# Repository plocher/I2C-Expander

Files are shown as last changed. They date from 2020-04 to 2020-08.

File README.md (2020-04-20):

# I2C-9555
## License: CERN Open Hardware Licence v1.2

I2C PCF9555 / or / MCP23017 -based IO Expander with 4x IOB connections

This board can host either the MCP23017 or PCA9555 SO package chips.
The difference in proice is slight (~$0.50 or less), but the chips have slightly different programming and 
features, which may make one more desirable.  Rather than support 2x designs, it is easier to have one.

This is a 16-bit I/O board with 2x 8-bit ports: port0 and port1.

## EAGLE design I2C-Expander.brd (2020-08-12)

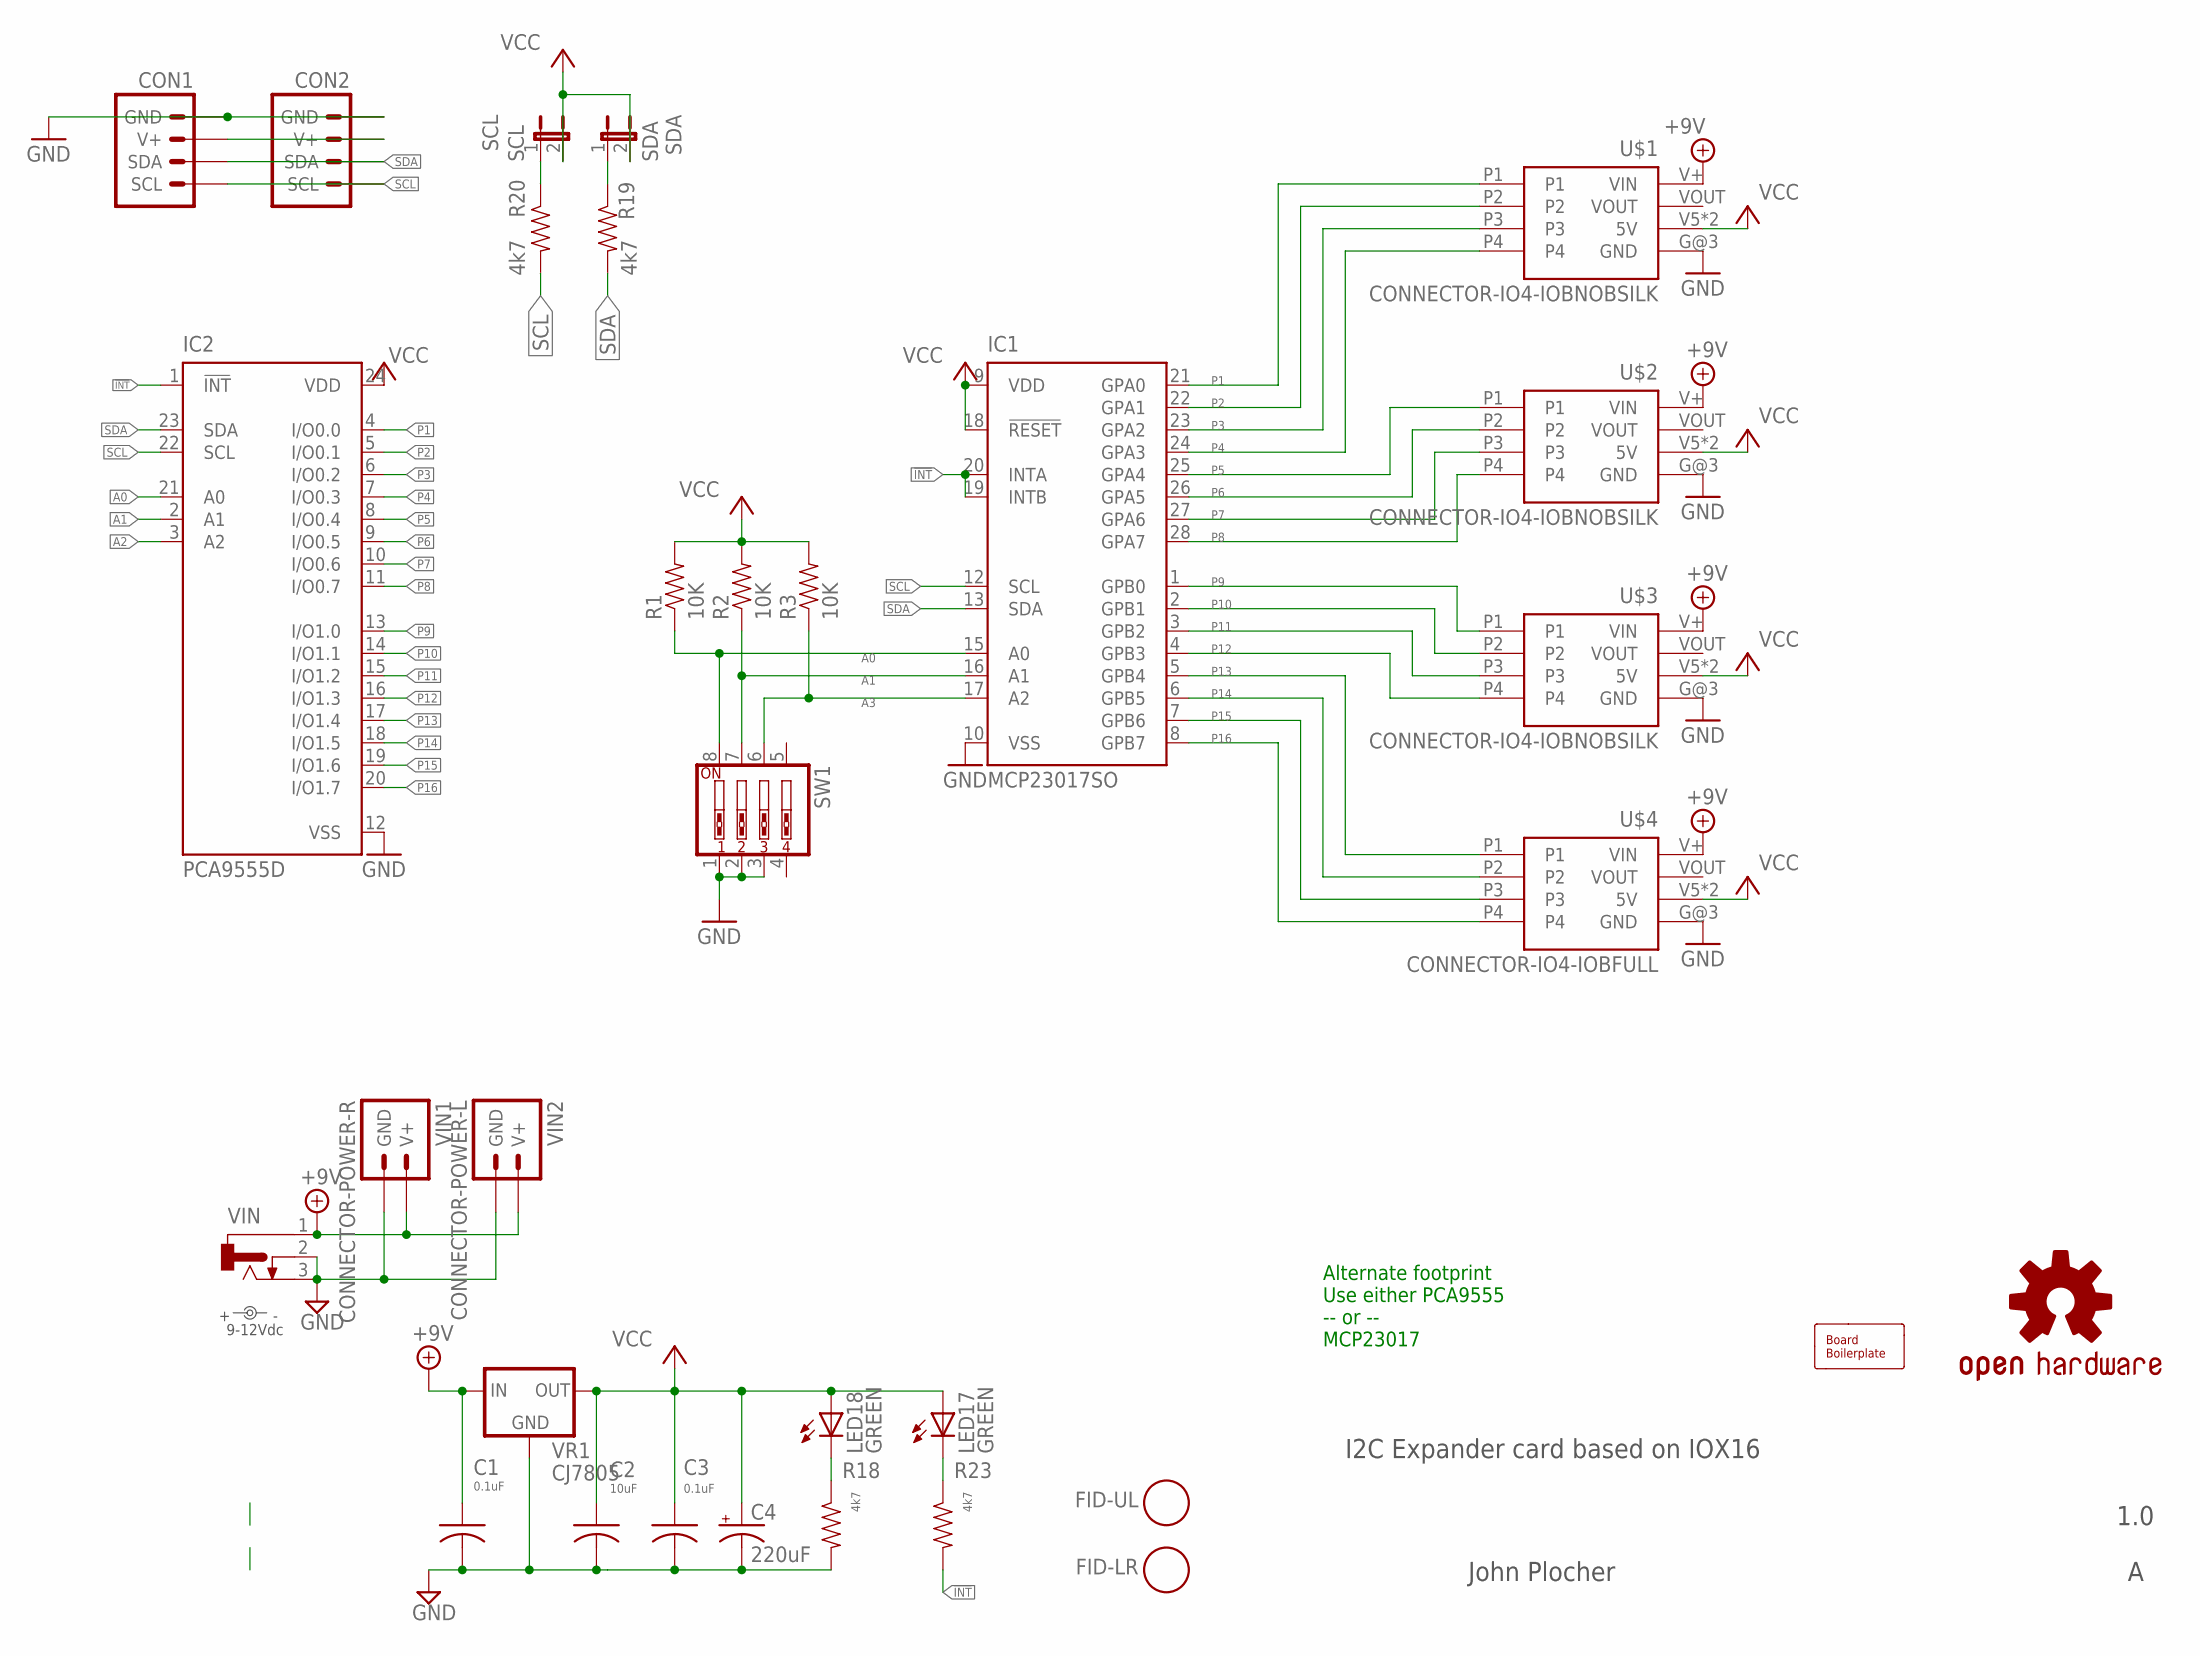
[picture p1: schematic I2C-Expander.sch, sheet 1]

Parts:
BOARD1: BOARD80X100-IOB; BOARD-DINRAIL-3.17IN-IOB
C1, C3: 0.1uF; 0805-CAP
C2: 10uF; 0805-CAP
C4: 220uF; 0810-CAP
CON1, CON2: CONNECTOR-I2CLEFT; I2C-L
FID-LR: FIDUCIAL; FIDUCIAL_1MM
FID-UL: FIDUCIAL; FIDUCIAL_1MM
IC1: MCP23017SO; SO28W
IC2: PCA9555D; SO24
LED17, LED18: GREEN; 0603-LED
OSHW1: DOC-OSHW-LOGO-M; OSHW-LOGO-M
POWER: 9-12Vdc; PWR_LABEL
R1, R2, R3: 10K; 0603-RES
R18, R19, R20, R23: 4k7; 0603-RES
SCL: SCL; 1X02_LOCK
SDA: SDA; 1X02_LOCK
SW1: SW_DIP-4; EDG-04
U$1, U$2, U$3: CONNECTOR-IO4-IOBNOBSILK; IOB-IO4-NOBOTSILK
U$4: CONNECTOR-IO4-IOBFULL; IO4-IOB
VIN: CONNECTOR-DC-POWER-RA; DCJ0202
VIN1: CONNECTOR-POWER-R; POWER-R
VIN2: CONNECTOR-POWER-L; POWER-R2
VR1: CJ7805; TO-252

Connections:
!INT: IC1.19 (INTB), IC1.20 (INTA), IC2.1 (!INT), R23.2
+9V: C1.1, U$1.V+ (VIN), U$2.V+ (VIN), U$3.V+ (VIN), U$4.V+ (VIN), VIN.1, VIN1.V+, VIN1.V+@1 (V+), VIN1.V+@2 (V+), VIN1.V+@3 (V+), VIN2.V+, VIN2.V+@1 (V+), VIN2.V+@2 (V+), VIN2.V+@3 (V+), VR1.1 (IN)
A0: IC1.15 (A0), IC2.21 (A0), R1.1, SW1.8
A1: IC1.16 (A1), IC2.2 (A1), R2.1, SW1.7
A2: IC2.3 (A2)
A3: IC1.17 (A2), R3.1, SW1.6
GND: C1.2, C2.2, C3.2, C4.-, CON1.GND, CON1.GND@1 (GND), CON2.GND, CON2.GND@1 (GND), IC1.10 (VSS), IC2.12 (VSS), R18.2, SW1.1, SW1.2, SW1.3, U$1.G@3 (GND), U$2.G@3 (GND), U$3.G@3 (GND), U$4.G@3 (GND), VIN.2, VIN.3, VIN1.GND, VIN1.GND@1 (GND), VIN1.GND@2 (GND), VIN1.GND@3 (GND), VIN2.GND, VIN2.GND@1 (GND), VIN2.GND@2 (GND), VIN2.GND@3 (GND), VR1.2 (GND); also elsewhere on the board
unnamed: CON1.V+, CON1.V+@1 (V+), CON2.V+, CON2.V+@1 (V+)
unnamed: LED17.C, R23.1
unnamed: R20.1, SCL.1
unnamed: R19.1, SDA.1
unnamed: LED18.C, R18.1
P1: IC1.21 (GPA0), IC2.4 (I/O0.0), U$1.P1; also elsewhere on the board
P2: IC1.22 (GPA1), IC2.5 (I/O0.1), U$1.P2; also elsewhere on the board
P3: IC1.23 (GPA2), IC2.6 (I/O0.2), U$1.P3; also elsewhere on the board
P4: IC1.24 (GPA3), IC2.7 (I/O0.3), U$1.P4; also elsewhere on the board
P5: IC1.25 (GPA4), IC2.8 (I/O0.4), U$2.P1; also elsewhere on the board
P6: IC1.26 (GPA5), IC2.9 (I/O0.5), U$2.P2; also elsewhere on the board
P7: IC1.27 (GPA6), IC2.10 (I/O0.6), U$2.P3; also elsewhere on the board
P8: IC1.28 (GPA7), IC2.11 (I/O0.7), U$2.P4; also elsewhere on the board
P9: IC1.1 (GPB0), IC2.13 (I/O1.0), U$3.P1; also elsewhere on the board
P10: IC1.2 (GPB1), IC2.14 (I/O1.1), U$3.P2; also elsewhere on the board
P11: IC1.3 (GPB2), IC2.15 (I/O1.2), U$3.P3; also elsewhere on the board
P12: IC1.4 (GPB3), IC2.16 (I/O1.3), U$3.P4; also elsewhere on the board
P13: IC1.5 (GPB4), IC2.17 (I/O1.4), U$4.P1; also elsewhere on the board
P14: IC1.6 (GPB5), IC2.18 (I/O1.5), U$4.P2; also elsewhere on the board
P15: IC1.7 (GPB6), IC2.19 (I/O1.6), U$4.P3; also elsewhere on the board
P16: IC1.8 (GPB7), IC2.20 (I/O1.7), U$4.P4; also elsewhere on the board
SCL: CON1.SCL, CON1.SCL@1 (SCL), CON2.SCL, CON2.SCL@1 (SCL), IC1.12 (SCL), IC2.22 (SCL), R20.2
SDA: CON1.SDA, CON1.SDA@1 (SDA), CON2.SDA, CON2.SDA@1 (SDA), IC1.13 (SDA), IC2.23 (SDA), R19.2
VCC: C2.1, C3.1, C4.+, IC1.9 (VDD), IC1.18 (!RESET), IC2.24 (VDD), LED17.A, LED18.A, R1.2, R2.2, R3.2, SCL.2, SDA.2, U$1.V5 (5V), U$1.V5@1 (5V), U$2.V5 (5V), U$2.V5@1 (5V), U$3.V5 (5V), U$3.V5@1 (5V), U$4.V5 (5V), U$4.V5@1 (5V), VR1.3 (OUT); also elsewhere on the board

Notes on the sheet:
I2C Expander card based on IOX16
1.0
John Plocher
Alternate footprint Use either PCA9555 -- or -- MCP23017

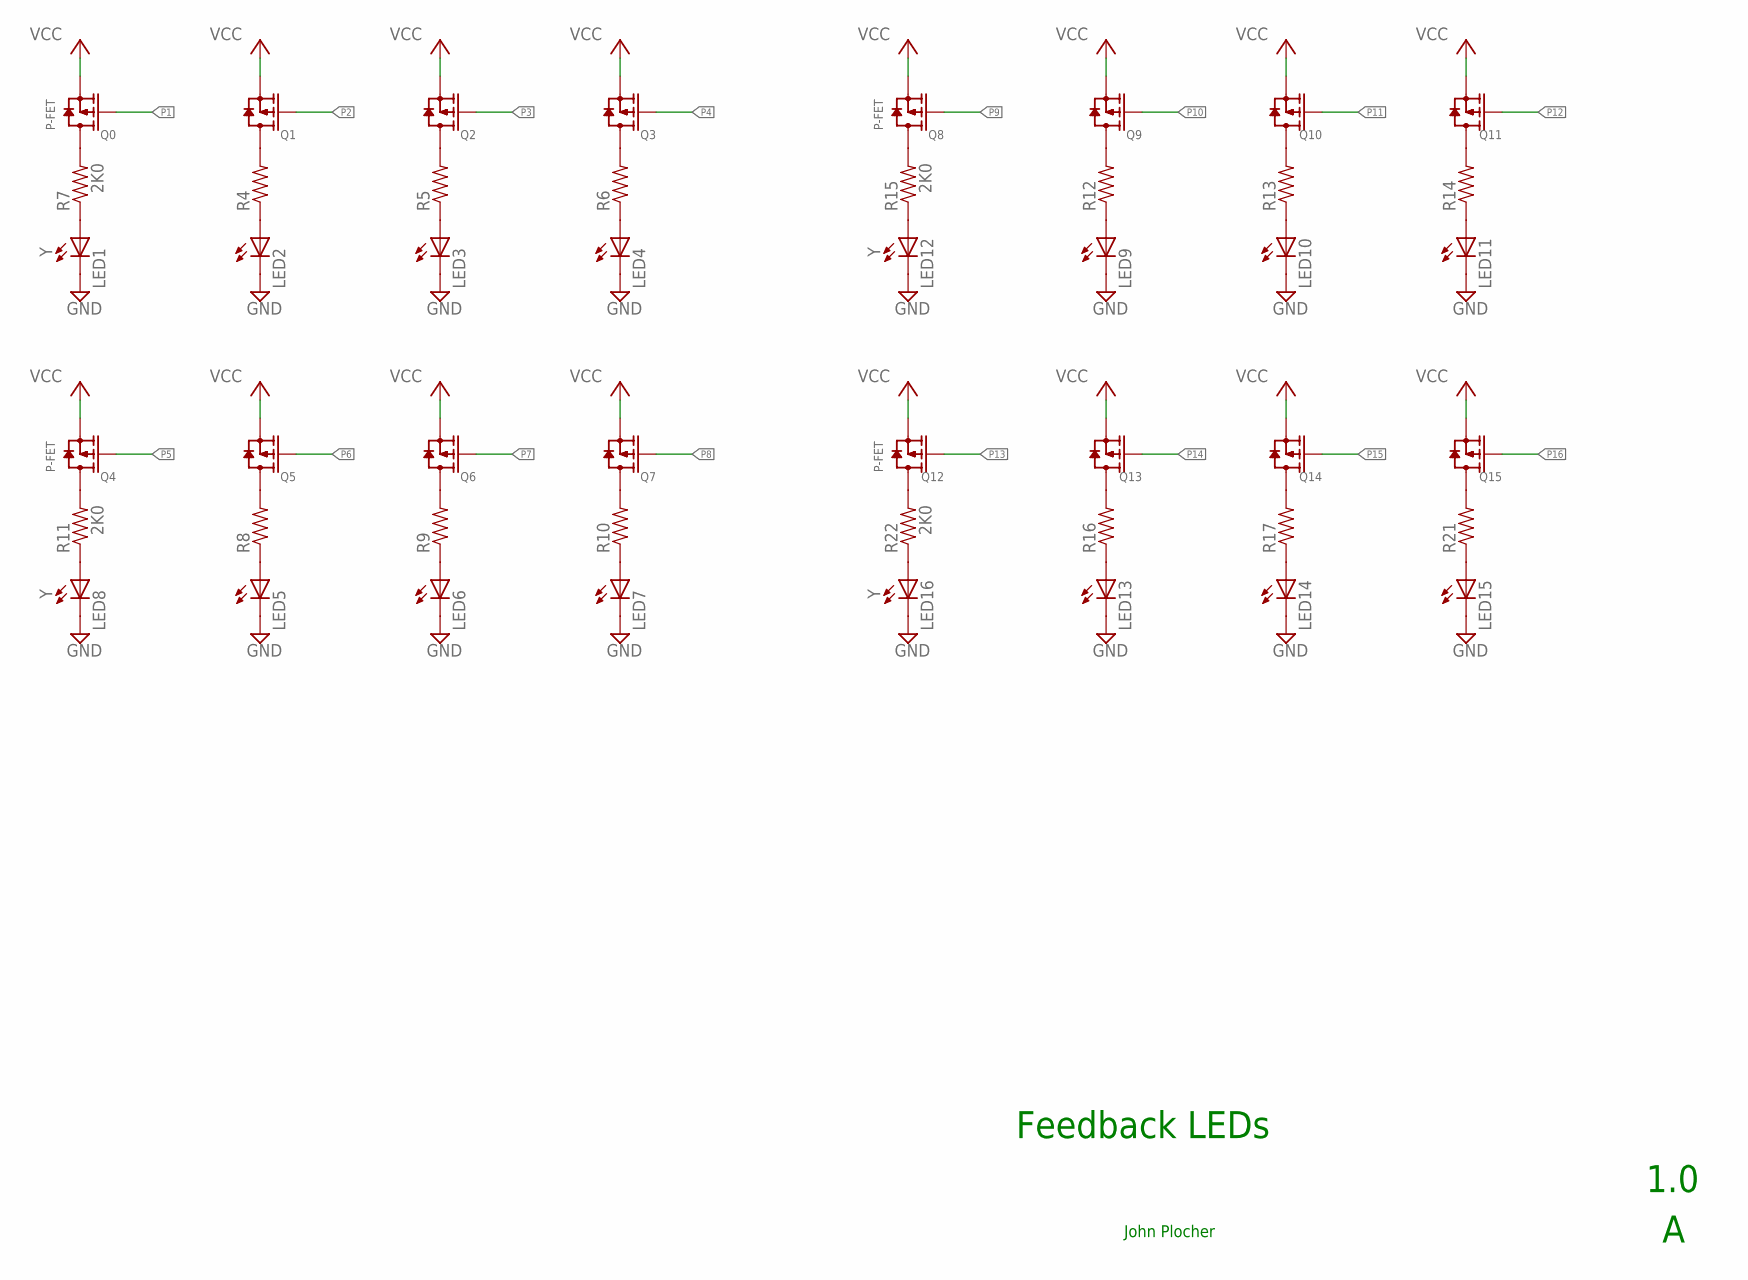
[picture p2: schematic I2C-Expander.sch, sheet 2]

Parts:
LED1, LED2, LED3, LED4, LED5, LED6, LED7, LED8, LED9, LED10, LED11, LED12, LED13, LED14, LED15, LED16: Y; 0603-LED
Q0, Q1, Q2, Q3, Q4, Q5, Q6, Q7, Q8, Q9, Q10, Q11, Q12, Q13, Q14, Q15: P-FET; SOT23
R4, R5, R6, R7, R8, R9, R10, R11, R12, R13, R14, R15, R16, R17, R21, R22: 2K0; 0805-RES

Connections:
GND: LED1.C, LED2.C, LED3.C, LED4.C, LED5.C, LED6.C, LED7.C, LED8.C, LED9.C, LED10.C, LED11.C, LED12.C, LED13.C, LED14.C, LED15.C, LED16.C; also elsewhere on the board
unnamed: Q4.3 (D), R11.2
unnamed: Q5.3 (D), R8.2
unnamed: Q6.3 (D), R9.2
unnamed: Q7.3 (D), R10.2
unnamed: LED8.A, R11.1
unnamed: LED5.A, R8.1
unnamed: LED6.A, R9.1
unnamed: LED7.A, R10.1
unnamed: Q8.3 (D), R15.2
unnamed: Q9.3 (D), R12.2
unnamed: Q10.3 (D), R13.2
unnamed: Q11.3 (D), R14.2
unnamed: LED12.A, R15.1
unnamed: LED9.A, R12.1
unnamed: LED10.A, R13.1
unnamed: LED11.A, R14.1
unnamed: Q12.3 (D), R22.2
unnamed: Q13.3 (D), R16.2
unnamed: Q14.3 (D), R17.2
unnamed: Q15.3 (D), R21.2
unnamed: LED16.A, R22.1
unnamed: LED13.A, R16.1
unnamed: LED14.A, R17.1
unnamed: LED15.A, R21.1
unnamed: Q0.3 (D), R7.2
unnamed: Q1.3 (D), R4.2
unnamed: Q2.3 (D), R5.2
unnamed: Q3.3 (D), R6.2
unnamed: LED1.A, R7.1
unnamed: LED2.A, R4.1
unnamed: LED3.A, R5.1
unnamed: LED4.A, R6.1
P1: Q0.1 (G); also elsewhere on the board
P2: Q1.1 (G); also elsewhere on the board
P3: Q2.1 (G); also elsewhere on the board
P4: Q3.1 (G); also elsewhere on the board
P5: Q4.1 (G); also elsewhere on the board
P6: Q5.1 (G); also elsewhere on the board
P7: Q6.1 (G); also elsewhere on the board
P8: Q7.1 (G); also elsewhere on the board
P9: Q8.1 (G); also elsewhere on the board
P10: Q9.1 (G); also elsewhere on the board
P11: Q10.1 (G); also elsewhere on the board
P12: Q11.1 (G); also elsewhere on the board
P13: Q12.1 (G); also elsewhere on the board
P14: Q13.1 (G); also elsewhere on the board
P15: Q14.1 (G); also elsewhere on the board
P16: Q15.1 (G); also elsewhere on the board
VCC: Q0.2 (S), Q1.2 (S), Q2.2 (S), Q3.2 (S), Q4.2 (S), Q5.2 (S), Q6.2 (S), Q7.2 (S), Q8.2 (S), Q9.2 (S), Q10.2 (S), Q11.2 (S), Q12.2 (S), Q13.2 (S), Q14.2 (S), Q15.2 (S); also elsewhere on the board

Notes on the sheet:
Feedback LEDs
1.0
John Plocher

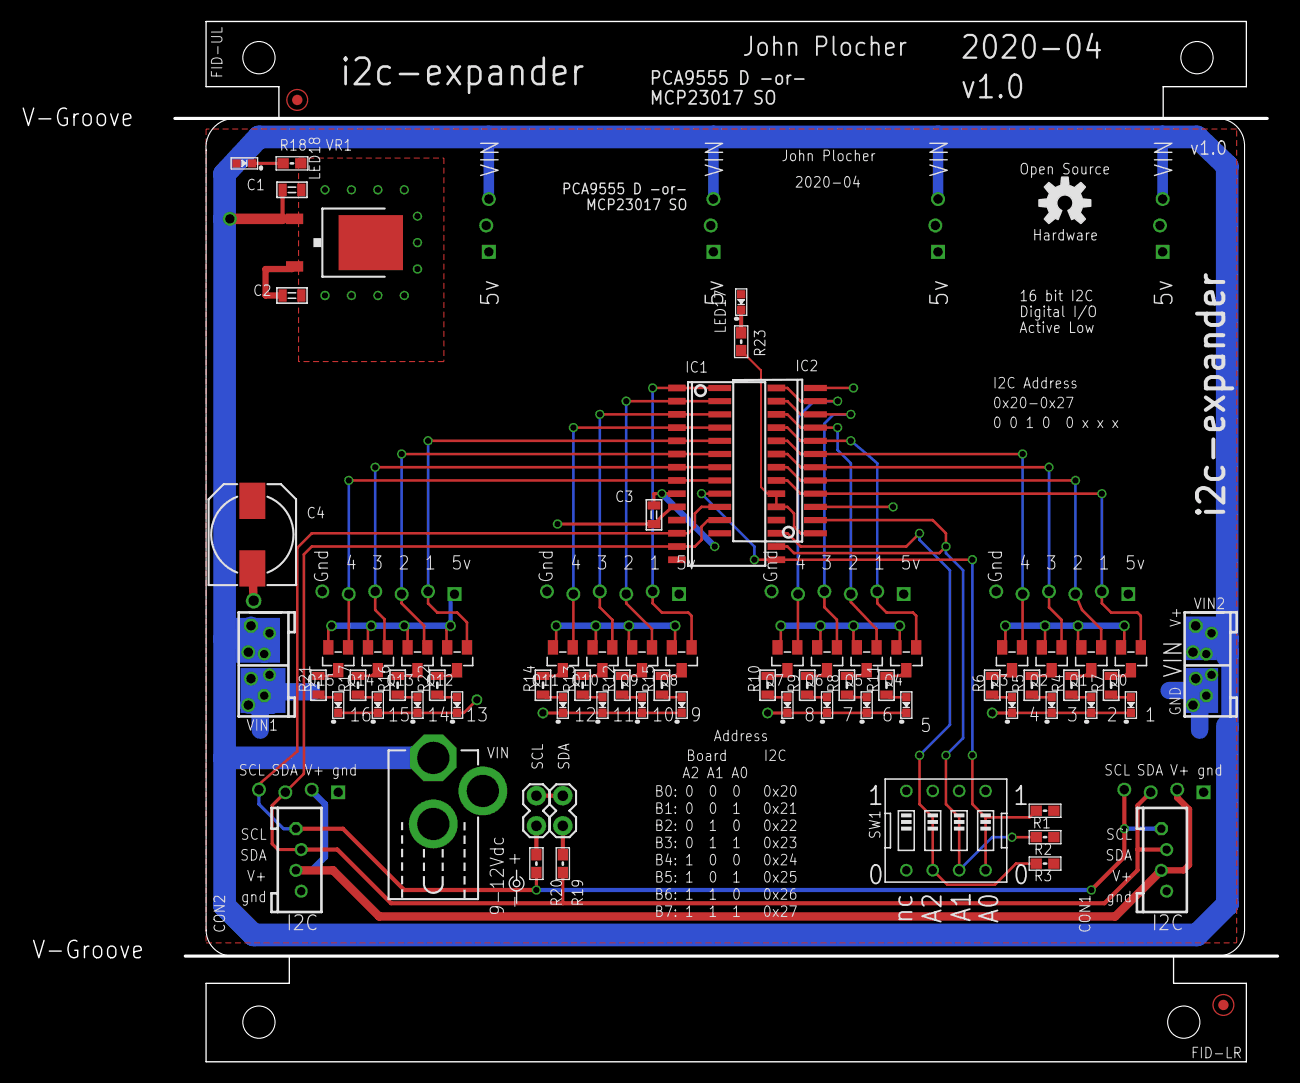
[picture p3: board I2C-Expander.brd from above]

Board: 2 copper layers, 106.0 x 100.0 mm, 81 parts (0 on the bottom side), 62 nets.

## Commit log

2020-04-20 Initial version
    [I2C-Expander.brd, I2C-Expander.sch]
2020-04-23 added LED on input changed interrupt pins
    [I2C-Expander.brd, I2C-Expander.sch]
2020-08-05 fixed SPCoast lbr part orientation
    [I2C-Expander.brd, I2C-Expander.sch]
2020-08-06 more silkscreen updates
    [I2C-Expander.brd]
2020-08-12 FID placement & names
    [I2C-Expander.brd, I2C-Expander.sch]

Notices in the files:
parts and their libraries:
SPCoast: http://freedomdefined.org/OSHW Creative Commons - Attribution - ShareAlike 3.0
